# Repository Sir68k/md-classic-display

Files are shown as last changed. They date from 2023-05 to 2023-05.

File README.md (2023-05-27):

# md-classic-display

This project is a modern replacement for classic LCD displays in Sony MiniDisc portables. It uses an ATTiny1614 controller with a TPS61046 boost circuit for driving an SSD1306 OLED.

The protocol is documented here: https://github.com/MiniDisc-wiki/md-firmware/wiki/LCD-SPI-protocol-(NetMD-devices)

Confirmed to work with: MZ-N510, MZ-N520, MZ-N505. Should work on all Sony NetMD devices (non-himd), and most likely will work on older devices (the MZ-R700 uses the exact samedisplay protocol, I only haven't tested it).

## How to use

Connect the OLED board to the SPI lines on the MD display board. VCC on the display board isn't stable enough, you should connect to a stable voltage line on the MD controller board (such as VCC for the remote, VCO1 on the MZ-N510).

## What needs to be improved

- I haven't implemented custom glyph support yet, so my tetris / raycaster demos will not work with this display
- There can be minor lag between two display updates, which sometimes is visible when text is scrolling. Can be fixed by updating the display in a slightly smarter way.
- Themes would be cool

## Photos 

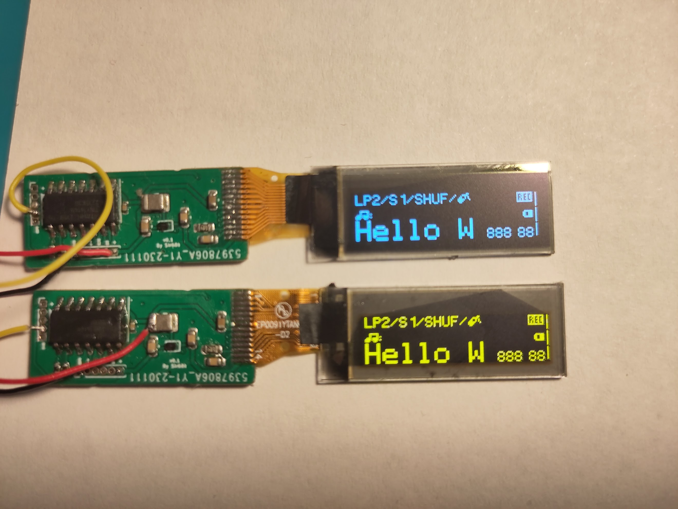
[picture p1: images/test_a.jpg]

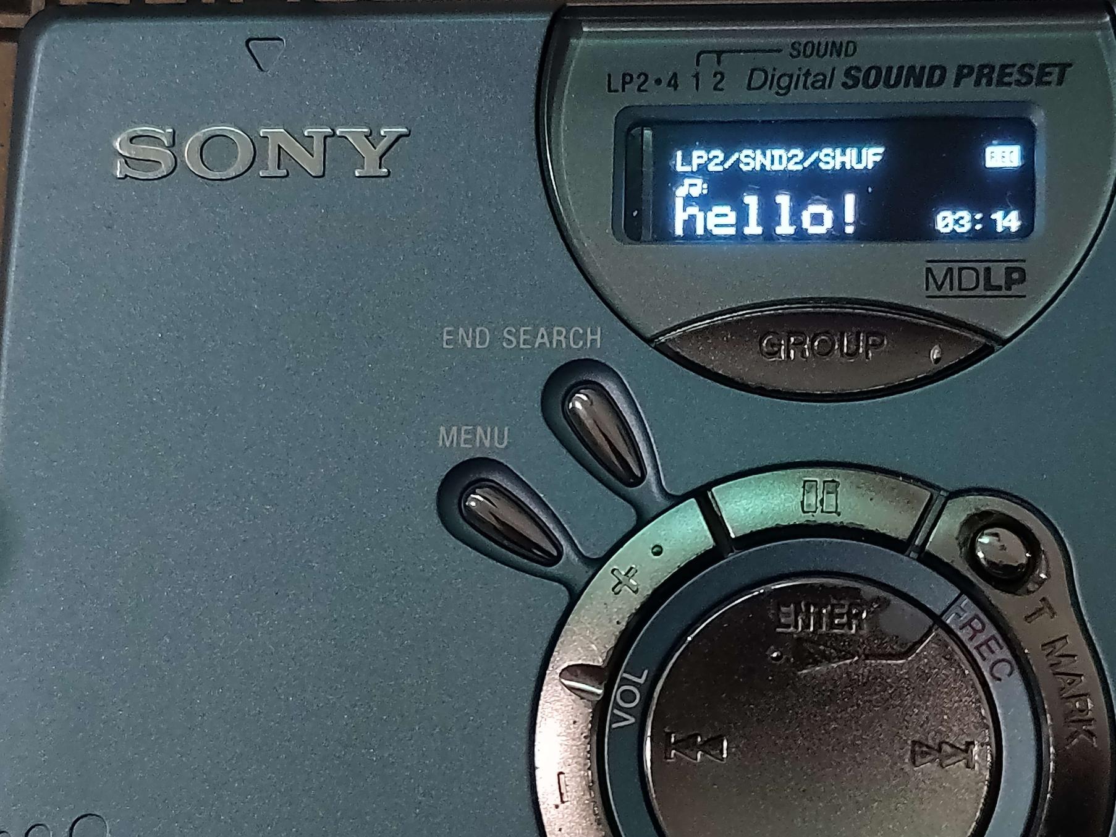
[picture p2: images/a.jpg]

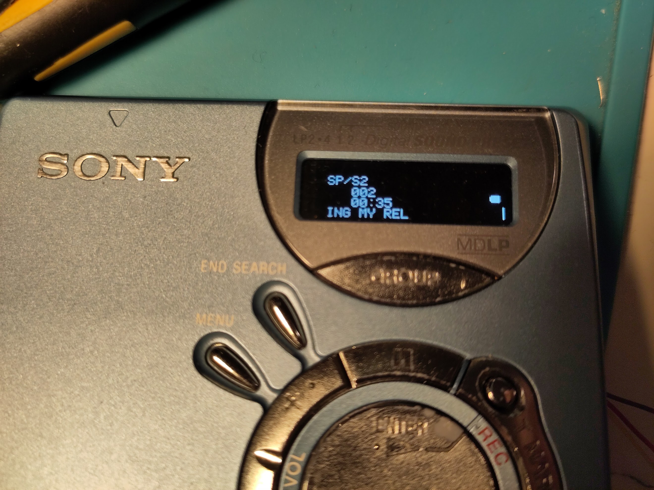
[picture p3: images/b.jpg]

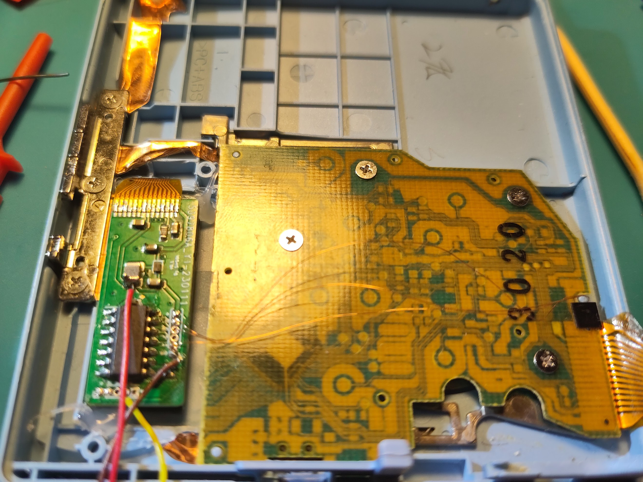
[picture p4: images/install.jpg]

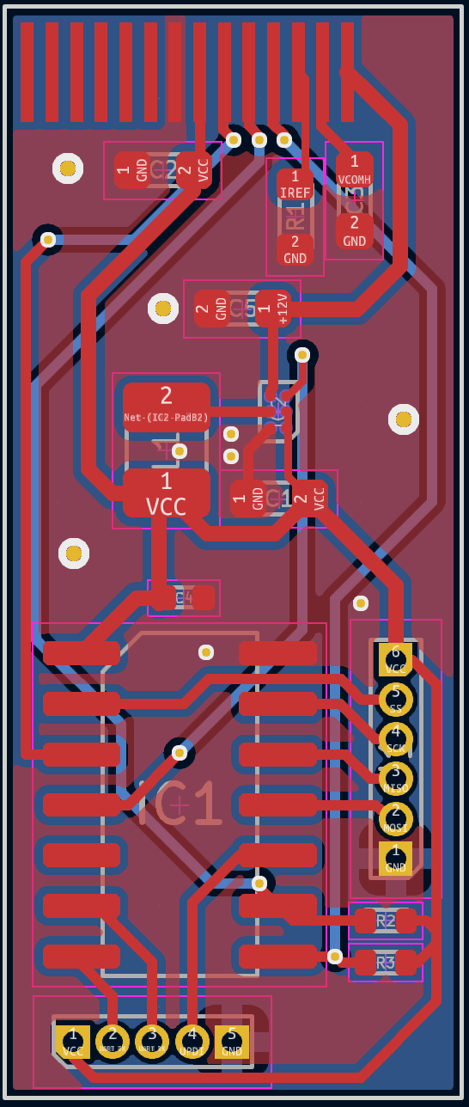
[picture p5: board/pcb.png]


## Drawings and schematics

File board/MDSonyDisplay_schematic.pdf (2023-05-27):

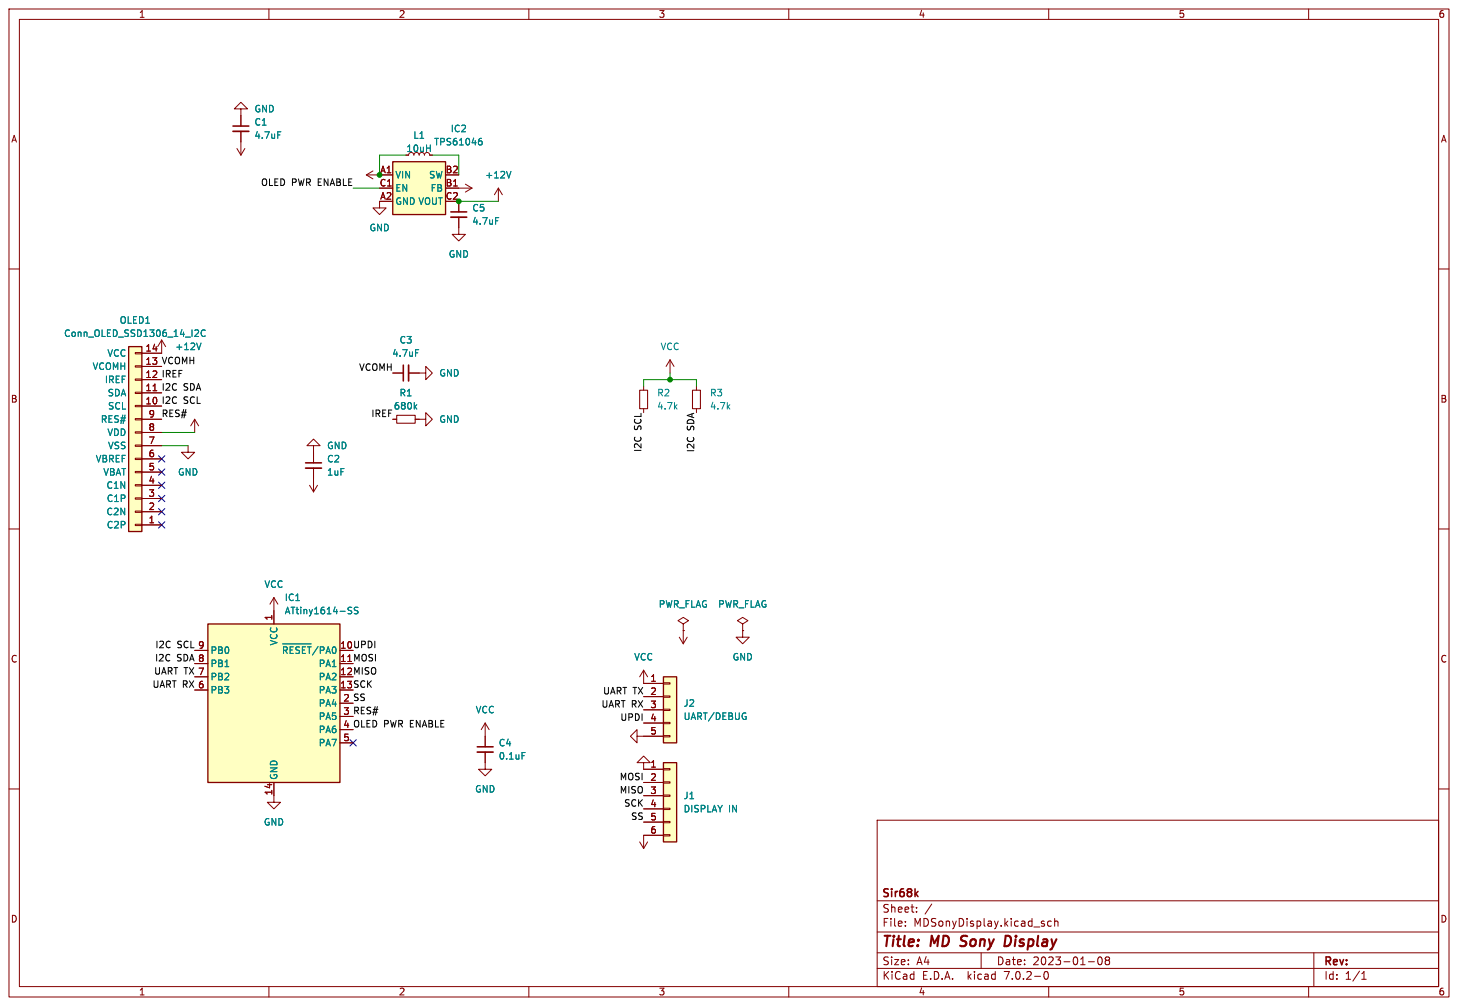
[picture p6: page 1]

SSUPDI
RES# OLED PWR ENABLE MOSI
SCK MISO

Id: 1/1 Title: MD Sony Display

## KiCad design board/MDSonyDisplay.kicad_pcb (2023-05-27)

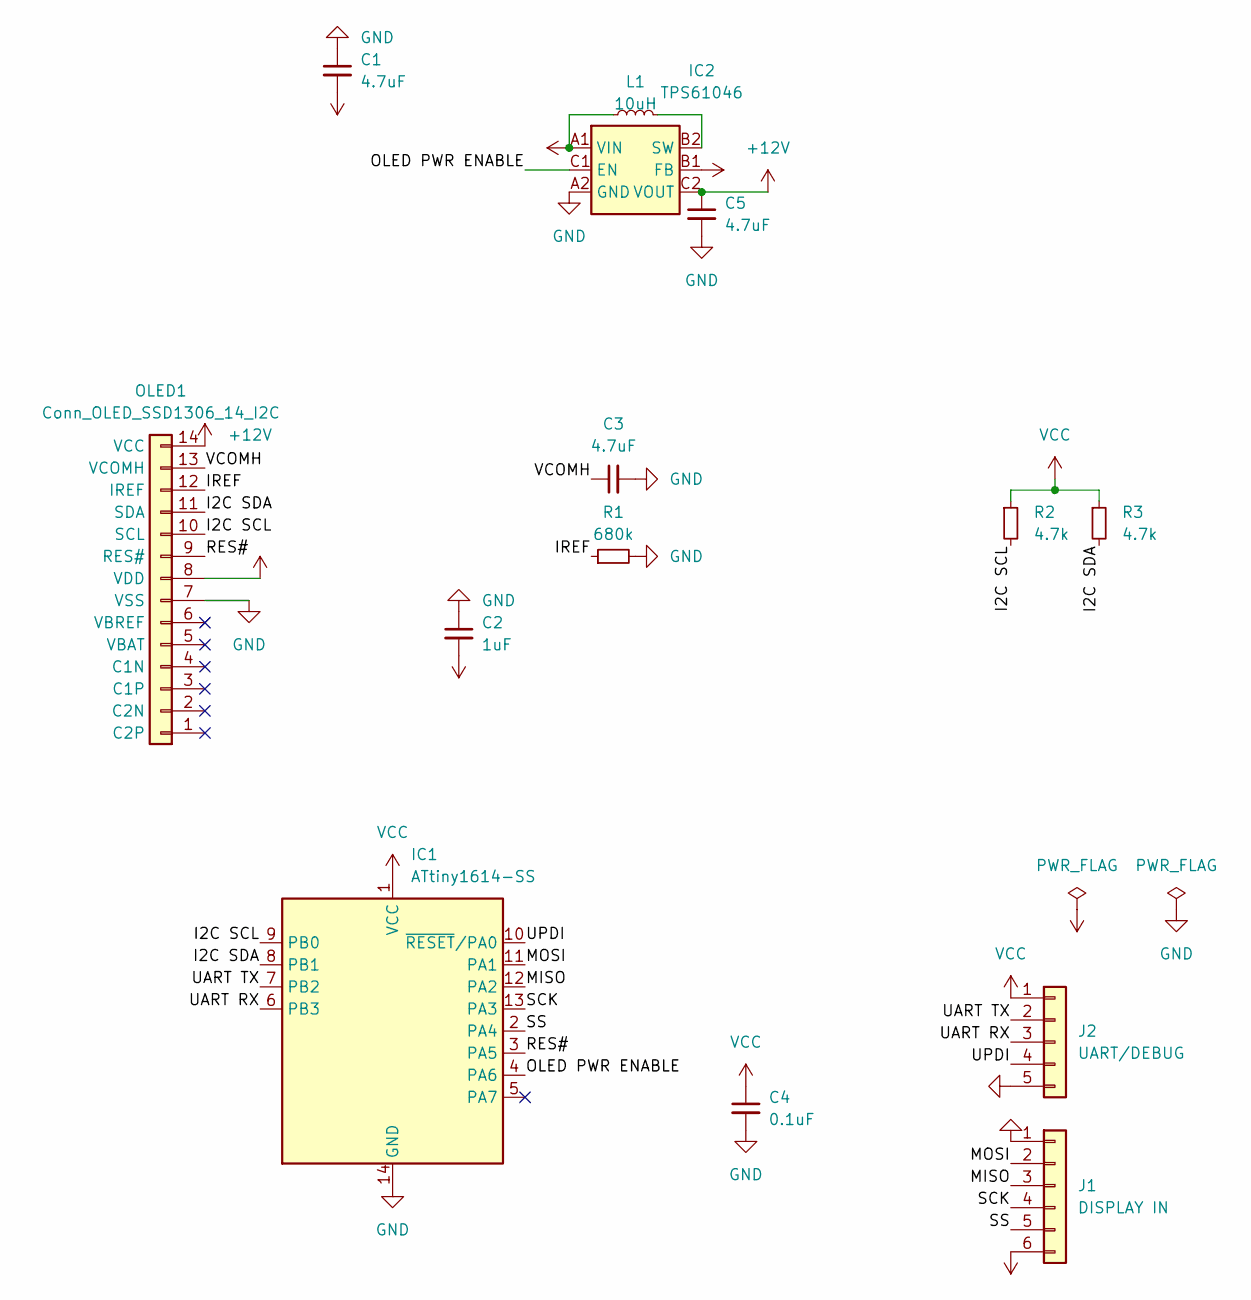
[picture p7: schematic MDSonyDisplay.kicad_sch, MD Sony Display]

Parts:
C1, C3, C5: 4.7uF; C_0603_1608Metric
C2: 1uF; C_0603_1608Metric
C4: 0.1uF; C_0402_1005Metric
IC1: ATtiny1614-SS; SOIC-14_3.9x8.7mm_P1.27mm
IC2: TPS61046; Texas_DSBGA-6_0.95x1.488mm_Layout2x3_P0.4mm
J1: DISPLAY IN; PinHeader_1x06_P1.00mm_Vertical
J2: UART/DEBUG; PinHeader_1x05_P1.00mm_Vertical
L1: 10uH; L_1008_2520Metric
OLED1: Conn_OLED_SSD1306_14_I2C; Connector_OLED_SSD1306_UT-0206-P02
R1: 680k; R_0603_1608Metric
R2, R3: 4.7k; R_0402_1005Metric

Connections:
+12V: C5.1, IC2.C2 (VOUT), OLED1.14 (VCC)
/I2C SCL: IC1.9 (PB0), OLED1.10 (SCL), R2.2
/I2C SDA: IC1.8 (PB1), OLED1.11 (SDA), R3.2
/IREF: OLED1.12 (IREF), R1.1
/MISO: IC1.12 (PA2), J1.3
/MOSI: IC1.11 (PA1), J1.2
/OLED PWR ENABLE: IC1.4 (PA6), IC2.C1 (EN)
/RES#: IC1.3 (PA5), OLED1.9 (RES#)
/SCK: IC1.13 (PA3), J1.4
/SS: IC1.2 (PA4), J1.5
/UART RX: IC1.6 (PB3), J2.3
/UART TX: IC1.7 (PB2), J2.2
/UPDI: IC1.10 (~RESET/PA0), J2.4
/VCOMH: C3.1, OLED1.13 (VCOMH)
GND: C1.1, C2.1, C3.2, C4.2, C5.2, IC1.14 (GND), IC2.A2 (GND), J1.1, J2.5, OLED1.7 (VSS), R1.2
unnamed: IC2.B2 (SW), L1.2
VCC: C1.2, C2.2, C4.1, IC1.1 (VCC), IC2.A1 (VIN), IC2.B1 (FB), J1.6, J2.1, L1.1, OLED1.8 (VDD), R2.1, R3.1

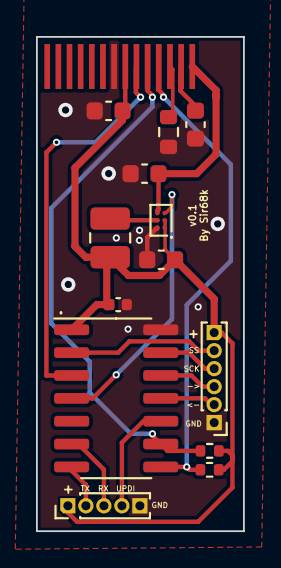
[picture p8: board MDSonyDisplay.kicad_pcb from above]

Board: 2 copper layers, 11.5 x 27.5 mm, 14 parts (0 on the bottom side), 17 nets.

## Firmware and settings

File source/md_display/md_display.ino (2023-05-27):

#include "oled.hpp"
#include "lcd_emu.h"
#include "icons.h"

#include <SPI.h>
#include <avr/io.h>
#include <avr/interrupt.h>

///////////
/// SPI ///
///////////

void SPI0_init(void);

/* SPI as Slave
 * Pin Assignment
 * 2. PA4 : SS
 * 11.PA1 : MOSI
 * 12.PA2 : MISO
 * 13.PA3 : SCK
 */
 
#define MOSI_bp 1
#define MOSI_bm (1 << MOSI_bp)
#define MISO_bp 2
#define MISO_bm (1 << MISO_bp)

#define SCK_bp 3
#define SCK_bm (1 << SCK_bp)
#define SS_bp 4
#define SS_bm (1 << SS_bp)


void SPI0_init(void) 
{
  PORTA.DIRSET = MISO_bm;

  SPI0.CTRLB = SPI_MODE3;
  SPI0.CTRLA = SPI_DORD_bm    /* LSB is transmitted first */
    | SPI_ENABLE_bm           /* Enable module */
    | (!SPI_MASTER_bm);       /* SPI module in Slave mode */
    SPI0.INTCTRL = SPI_IE_bm; /* SPI Interrupt enable */
}

ISR(SPI0_INT_vect)
{
  //uint8_t receiveData = SPI0.DATA;
  lcd_byte_in((uint8_t)SPI0.DATA);
  SPI0.DATA = 0;
  SPI0.INTFLAGS = SPI_IF_bm; /* Clear the Interrupt flag by writing 1 */
}

//////////
// OLED //
//////////

OLED<SSD1306_128x32> oled;

///////////
// SETUP //
///////////

void setup() {
  //Serial.begin(9600);

  SPI0_init();
  sei();

  pinMode(PIN_PA6, OUTPUT);
  digitalWrite(PIN_PA6, HIGH);


  pinMode(PIN_PA5, OUTPUT);
  digitalWrite(PIN_PA5, LOW);
  

  delay(100);
  digitalWrite(PIN_PA5, HIGH);
  
  oled.init();
  oled.flipV(1);
  oled.flipH(1);


  lcd_init();

  oled_intro();
  delay(250);
}

void oled_intro() {
  set_text_memory(0, 6, "Hello ");
  set_text_memory(6, 6, "World!");
  
  lcd_set_symbol(LCD_SYM_LP2, 1);
  lcd_set_symbol(LCD_SYM_MELODY, 1);
  lcd_set_symbol(LCD_SYM_REC, 1);
  lcd_set_symbol(LCD_SYM_SHUF, 1);
  lcd_set_symbol(LCD_SYM_SOUND1, 1);
  lcd_set_symbol(LCD_SYM_BOOKMARKED, 1);  

  lcd_set_symbol(LCD_SYM_BAT_BOX, 1);
  lcd_set_symbol(LCD_SYM_BAT_2, 1);
  
  lcd_set_symbol(LCD_SYM_DISC_1, 1);
  lcd_set_symbol(LCD_SYM_DISC_2, 1);
  lcd_set_symbol(LCD_SYM_DISC_3, 1);
  
  display_n510();
}

void loop() {
  display_n510();
}


void display_n510() {
  uint8_t  shift     = lcd_get_shift();

  oled.clear();
  oled.home();

  oled.setScale(1);

  ////////////////
  // AUDIO TYPE //
  ////////////////
    
  if (lcd_get_symbol(LCD_SYM_MONO))
    oled.drawString("MONO");
  else if (lcd_get_symbol(LCD_SYM_LP2))
    oled.drawString("LP2");
  else if (lcd_get_symbol(LCD_SYM_LP4))
    oled.drawString("LP4");
  else
    oled.drawString("SP");

  ////////////////////
  // SOUND SETTINGS //
  ////////////////////

  if (lcd_get_symbol(LCD_SYM_SOUND1))
    oled.drawString("/S1");
  else if (lcd_get_symbol(LCD_SYM_SOUND2))
    oled.drawString("/S2");

  ///////////////
  // PLAY MODE //
  ///////////////

  if (lcd_get_symbol(LCD_SYM_SHUF))
    oled.drawString("/SHUF");
  else if (lcd_get_symbol(LCD_SYM_REPEAT))
    oled.drawString("/REP");
  else if (lcd_get_symbol(LCD_SYM_SINGLE))
    oled.drawString("/1");

  ///////////
  // OTHER //
  ///////////

  if (lcd_get_symbol(LCD_SYM_SYNC))
    oled.drawString("/SYNC");

  if (lcd_get_symbol(LCD_SYM_BOOKMARKED))
    oled.drawString("/\xA3\xA4"); // bookmark char
  
  /////////
  // REC //
  /////////
  
  if (lcd_get_symbol(LCD_SYM_REC)) {
    oled.setCursorXY(128-14, 0);
    oled.drawString("\x98\x99"); // rec char
  }

  /////////////
  // BATTERY //
  /////////////



  if (lcd_get_symbol(LCD_SYM_BAT_BOX)) {
      uint8_t* battery_icon;

     if (lcd_get_symbol(LCD_SYM_BAT_4))
      battery_icon = icons_7x7[9];
     else if (lcd_get_symbol(LCD_SYM_BAT_3))
      battery_icon = icons_7x7[10];
     else if (lcd_get_symbol(LCD_SYM_BAT_2))
      battery_icon = icons_7x7[11];
     else if (lcd_get_symbol(LCD_SYM_BAT_1))
      battery_icon = icons_7x7[12];
     else
      battery_icon = icons_7x7[13];

     oled.drawIcon7(battery_icon, 118, 12);
  }


  //oled.drawIcon7(icons_7x7[4], 110, 11);

  /////////////////
  // DISC STATUS //
  /////////////////

  if (lcd_get_symbol(LCD_SYM_DISC_1))
    oled.fastLineV(127, 0, 9);

  if (lcd_get_symbol(LCD_SYM_DISC_2))
    oled.fastLineV(127, 11, 20);

  if (lcd_get_symbol(LCD_SYM_DISC_3))
    oled.fastLineV(127, 22, 31);

  ////////////////
  // LABEL MODE //
  ////////////////


  oled.setCursorXY(0, 10);
  
  if (lcd_get_symbol(LCD_SYM_MELODY))
    oled.drawString("\x94\x95"); // melody char
  if (lcd_get_symbol(LCD_SYM_FOLDER))
    oled.drawString("\x92\x93"); // folder char
  
  /////////////////////
  // NUMBER SEGMENTS //
  /////////////////////
  
  draw7segment(92+ 0, 25, 0x7f);//lcd_get_7segment(1));
  draw7segment(92+ 6, 25, 0x7f);//lcd_get_7segment(2));
  draw7segment(92+12, 25, 0x7f);//lcd_get_7segment(3));

  if (lcd_get_symbol(LCD_SYM_SEG_COL)) {
    oled.setCursorXY(92+17, 25);
    oled.drawString(":");
  }

  draw7segment(92+22, 25, 0x7f);//lcd_get_7segment(4));
  draw7segment(92+28, 25, 0x7f);//lcd_get_7segment(5));
  
  ///////////////
  // TEXT DATA //
  ///////////////

  
  oled.setScale(2);
  oled.setCursorXY(0, 18);
  
  uint8_t* txt = lcd_get_text_data(0);
  for (int i=0; i<7; i++) {
    oled.drawChar(txt[i]);  
  }


  /*
  for (int r=0; r<3; r++) { 
    oled.setCursorXY(0, 9 + r*8);
    uint8_t* txt = lcd_get_text_data(r);
    
    for (int i=0; i<10; i++) {
      oled.drawChar(txt[i]);  
    }
  }*/
  
  oled.update();
  delay(10);
}

void draw7segment(uint8_t x, uint8_t y, uint8_t v) {

  // top segment
  if (v & 0b0000001){
    oled.dot(x+1, y, 1);  
    oled.dot(x+2, y, 1); 
    oled.dot(x+3, y, 1); 
  }

  // middle
  if (v & 0b0001000){
    oled.dot(x+1, y+3, 1);  
    oled.dot(x+2, y+3, 1); 
    oled.dot(x+3, y+3, 1); 
  }

  // bottom
  if (v & 0b1000000){
    oled.dot(x+1, y+6, 1);  
    oled.dot(x+2, y+6, 1); 
    oled.dot(x+3, y+6, 1); 
  }

  // top right
  if (v & 0b0000010){
    oled.dot(x+4, y+1, 1);  
    oled.dot(x+4, y+2, 1); 
  }

  // top left
  if (v & 0b0000100){
    oled.dot(x, y+1, 1);  
    oled.dot(x, y+2, 1); 
  }

  // bottom right
  if (v & 0b0010000){
    oled.dot(x+4, y+4, 1);  
    oled.dot(x+4, y+5, 1); 
  }

  // bottom left
  if (v & 0b0100000){
    oled.dot(x, y+4, 1);  
    oled.dot(x, y+5, 1); 
  }
}

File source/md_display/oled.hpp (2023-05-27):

/*
    Minimal SSD1306 OLED display routines and driver code

    Based on code from:

    GyverOled
    AlexGyver, alex@alexgyver.ru
    https://alexgyver.ru/
    MIT License

*/

#include <Wire.h>
#include "sony_font.h"

#define SSD1306_128x32   0
#define SSD1306_128x64   1

#define OLED_I2C 0
#define OLED_SPI 1

#define OLED_NO_BUFFER 0
#define OLED_BUFFER    1

#define OLED_CLEAR  0
#define OLED_FILL   1
#define OLED_STROKE 2

#define BUF_ADD      0
#define BUF_SUBTRACT 1
#define BUF_REPLACE  2

#define BITMAP_NORMAL 0
#define BITMAP_INVERT 1


#define OLED_WIDTH              128
#define OLED_HEIGHT_32          0x02
#define OLED_HEIGHT_64          0x12
#define OLED_64                 0x3F
#define OLED_32                 0x1F

#define OLED_DISPLAY_OFF        0xAE
#define OLED_DISPLAY_ON         0xAF

#define OLED_COMMAND_MODE       0x00
#define OLED_ONE_COMMAND_MODE   0x80
#define OLED_DATA_MODE          0x40
#define OLED_ONE_DATA_MODE      0xC0

#define OLED_ADDRESSING_MODE    0x20
#define OLED_HORIZONTAL         0x00
#define OLED_VERTICAL           0x01

#define OLED_NORMAL_V            0xC8
#define OLED_FLIP_V              0xC0
#define OLED_NORMAL_H            0xA1
#define OLED_FLIP_H              0xA0

#define OLED_CONTRAST           0x81
#define OLED_SETCOMPINS         0xDA
#define OLED_SETVCOMDETECT      0xDB
#define OLED_CLOCKDIV           0xD5
#define OLED_SETMULTIPLEX       0xA8
#define OLED_COLUMNADDR         0x21
#define OLED_PAGEADDR           0x22
#define OLED_CHARGEPUMP         0x8D

#define OLED_NORMALDISPLAY      0xA6
#define OLED_INVERTDISPLAY      0xA7

#define BUFSIZE_128x64 (128*64/8)
#define BUFSIZE_128x32 (128*32/8)

/////////////////////////////////////
// SSD1306 Initialization sequence //
/////////////////////////////////////

#define INIT_SEQ_LEN 15
static const uint8_t _oled_init[] = {
  OLED_DISPLAY_OFF,
  OLED_CLOCKDIV,
  0x80,    // value
  OLED_CHARGEPUMP,
  0x10,    // value -> 10 disable chargepump, 14 enable chargepump
  OLED_ADDRESSING_MODE,
  OLED_VERTICAL,
  OLED_NORMAL_H,
  OLED_NORMAL_V,
  OLED_CONTRAST,
  0x7F,    // contrast value -> can go to 7f
  OLED_SETVCOMDETECT,
  0x40,     // value
  OLED_NORMALDISPLAY,
  OLED_DISPLAY_ON,
};

template <int _TYPE> class OLED {

  public:
    OLED(uint8_t address = 0x3C) : _address(address) {}

    void init() {
      Wire.begin();

      beginCommand();
      for (uint8_t i = 0; i < INIT_SEQ_LEN; i++)
        sendByte(_oled_init[i]);
      endTransm();

      beginCommand();
      sendByte(OLED_SETCOMPINS);
      sendByte(_TYPE ? OLED_HEIGHT_64 : OLED_HEIGHT_32);
      sendByte(OLED_SETMULTIPLEX);
      sendByte(_TYPE ? OLED_64 : OLED_32);
      endTransm();

      setCursorXY(0, 0);
      setWindow(0, 0, _maxX, _maxRow);
    }

    void clear() {
      fill(0);
    }

    void setContrast(uint8_t value) {
      sendCommand(OLED_CONTRAST, value);
    }
    void setPower(bool mode)        {
      sendCommand(mode ? OLED_DISPLAY_ON : OLED_DISPLAY_OFF);
    }
    void flipH(bool mode)           {
      sendCommand(mode ? OLED_FLIP_H : OLED_NORMAL_H);
    }
    void invertDisplay(bool mode)   {
      sendCommand(mode ? OLED_INVERTDISPLAY : OLED_NORMALDISPLAY);
    }
    void flipV(bool mode)           {
      sendCommand(mode ? OLED_FLIP_V : OLED_NORMAL_V);
    }

    void drawChar(uint8_t chr, int x = -1, int y = -1) {
      if (x == -1) x = _x;
      if (y == -1) y = _y;

      if (chr < 16) {
        // ignore char mem for now
      } else {
        for (int yy = 0; yy < SONY_FONT_HEIGHT; yy++) {
          uint8_t row = _sonyFont[chr - 16][yy];
          for (int xx = 0; xx < SONY_FONT_WIDTH; xx++) {
            dot(x + xx * _scale, y + yy * _scale, (row >> (5 - xx)) & 1);
          }
        }
      }

      _x += SONY_FONT_WIDTH * _scale;
    }

    void drawString(const char* str, int x = -1, int y = -1) {
    
      if (x >= 0) _x = x;
      if (y >= 0) _y = y;

      while (*str != 0) {
        drawChar(*str);
        str++;
      }
    }

    void drawIcon7(uint8_t* icon, int x = -1, int y = -1) {
      if (x >= 0) _x = x;
      if (y >= 0) _y = y;

      for (int xx = 0; xx < 7; xx++) {
        uint8_t row = icon[xx];
        for (int yy = 0; yy < 7; yy++) {
          dot(x + xx * _scale, y + yy * _scale, (row >> yy) & 1);
        }
      }

      _x += 7 * _scale;
    }

    void home() {
      setCursorXY(0, 0);
    }

    void setCursor(int x, int y) {
      setCursorXY(x, y);
    }

    void setCursorXY(int x, int y) {
      _x = x;
      _y = y;
    }

    void setScale(uint8_t scale) {
      _scale = scale;
    }

    void invertText(bool inv) {
      _invState = inv;
    }
    void textMode(byte mode) {
      _mode = mode;
    }
    bool isEnd() {
      return (_y > _maxRow);
    }

    void dot(int x, int y, byte fill = 1) {
      for (int xx = 0; xx < _scale; xx++)
        for (int yy = 0; yy < _scale; yy++)
          dot_pure(x + xx, y + yy, fill);
    }

    void dot_pure(int x, int y, byte fill = 1) {
      if (x < 0 || x > _maxX || y < 0 || y > _maxY) return;

      bitWrite(_oled_buffer[_bufIndex(x, y)], y & 0b111, fill);
    }

    void fastLineH(int y, int x0, int x1, byte fill = 1) {
      _x = 0;
      _y = 0;

      if (x0 > x1)
        _swap(x0, x1);

      if (y < 0 || y > _maxY)
        return;

      if (x0 == x1) {
        dot(x0, y, fill);
        return;
      }

      x1++;
      x0 = constrain(x0, 0, _maxX);
      x1 = constrain(x1, 0, _maxX);

      for (int x = x0; x < x1; x++)
        dot(x, y, fill);
    }

    
    void fastLineV(int x, int y0, int y1, byte fill = 1) {
      _x = 0;
      _y = 0;

      if (y0 > y1)
        _swap(y0, y1);

      if (x < 0 || x > _maxX)
        return;

      if (y0 == y1) {
        dot(x, y0, fill);
        return;
      }

      y1++;
      y0 = constrain(y0, 0, _maxY);
      y1 = constrain(y1, 0, _maxY);

      for (int y = y0; y < y1; y++)
        dot(x, y, fill);
    }

    void fill(uint8_t data) {
      memset(_oled_buffer, data, _bufSize);
      setCursorXY(_x, _y);
    }

    void update() {
      setWindow(0, 0, _maxX, _maxRow);
      beginData();
      for (int i = 0; i < (_TYPE ? 1024 : 512); i++)
        sendByte(_oled_buffer[i]);
      endTransm();
    }

    void update(int x0, int y0, int x1, int y1) {
      y0 >>= 3;
      y1 >>= 3;

      setWindow(x0, y0, x1, y1);

      beginData();
      for (int x = x0; x < x1; x++)
        for (int y = y0; y < y1 + 1; y++)
          if (x >= 0 && x <= _maxX && y >= 0 && y <= _maxRow)
            sendByte(_oled_buffer[y + x * (_TYPE ? 8 : 4)]);
      endTransm();
    }
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
